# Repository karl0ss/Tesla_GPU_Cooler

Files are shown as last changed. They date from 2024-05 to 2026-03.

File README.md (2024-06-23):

# Tesla M60 GPU Cooler: An ESP8266-Based Solution for Nvidia Tesla Card Cooling

## Introduction

Starting a journey to build a cost-effective system for running large language models (LLMs) using [Ollama](https://ollama.com/) led me to discover Nvidia Tesla cards. These older cards, designed for server farms, boast substantial VRAM and are now available at affordable prices on eBay. After finding out that the Nvidia Tesla M60 supports Ollama and purchasing one, I realized these cards lack active cooling, necessitating a DIY solution for effective cooling.

## Overview of Existing Solutions

### 3D Printable Shroud with Dell Radial Fan

The first solution I encountered was a 3D printable shroud designed for the M40 card, which could be paired with a Dell radial fan. However, the shroud didn't fit my M60 due to dimensional differences and PSU connector placement. Modifying the Fusion 360 file, I created a shroud specifically for the M60. This design still required repinning the fan, which wasn't ideal as I lacked spare fan headers on my motherboard.

3D Printable Shroud

### PiPico-Based Fan Controller

The next project, [Tesla Cooler](https://github.com/tesla-cooler), used a PiPico and several small fans to cool the card. This setup controlled fan speed based on estimated temperatures derived from the `nvidia-smi` tool and a `ds18b20` temperature sensor. While innovative, I wanted a more accurate method for obtaining temperature readings and integrating them into Home Assistant.

PiPico-Based Fan Controller

### Sensors2mqtt for Accurate Temperature Readings

[Sensors2mqtt](https://github.com/koriwi/sensors2mqtt) provided a solution by scraping `nvidia-smi` data and posting it to an MQTT server, creating entities in Home Assistant. This approach offered the accuracy I needed without extensive coding, setting the foundation for my custom project.

## My Custom Solution

Integrating the best elements of these projects, I developed a comprehensive cooling system for the Tesla M60:

- **3D Printed Shroud**: Custom-designed to fit the M60, avoiding the need for repinning the fan.
- **Dell Fan**: Purchased from eBay, requiring no repinning.
- **ESP8266 Microcontroller**: Utilized for controlling the fan and connecting to Wi-Fi.
- **Nvidia SMI Data**: Used for accurate temperature readings.
- **DS18b20 Sensor**: Added as a fallback.
- **PID Controller Logic**: Maintains GPU temperature at 70°C, adjustable via Home Assistant.
- **Single 12V Line from ATX PSU**: Powers the 12V fan.
- **Custom PCB Design**: Designed a custom PCB for the ESP-12e to simplify the setup and ensure robust connections.

## The Implementation Plan

### Components and Tools

- **3D Printer**: To print the custom shroud.
- **Dell Radial Fan**: For active cooling.
- **ESP8266 (D1 Mini and ESP-12e)**: For microcontroller-based control.
- **Home Assistant**: For integration and control.
- **MQTT Server**: For data communication.
- **Nvidia SMI Tool**: For accurate temperature readings.
- **DS18b20 Temperature Sensor**: As a fallback option.
- **Custom PCB for ESP-12e**: To ensure reliable connections and ease of setup.

### Configuration with ESPHome and Home Assistant

Using [ESPHome](https://esphome.io/index.html), the ESP8266 microcontroller is configured to:

- **Connect to Wi-Fi**: Ensuring stable network communication.
- **Subscribe to MQTT Topics**: Receiving GPU temperature data.
- **Monitor Temperatures**: From both the GPU and DS18b20 sensor.
- **Control Fan Speed**: Based on temperature readings with predefined thresholds.
- **Integrate with Home Assistant**: Allowing manual override and monitoring.

### Detailed Configuration

The ESPHome YAML configuration includes several key components and functionalities:

#### Basic Setup
- **ESP8266 Microcontroller**: Configured for Wi-Fi connectivity and microcontroller operations.
- **Logger**: Enabled for logging events and debugging.
- **API and OTA**: Configured for Home Assistant API integration and over-the-air firmware updates.
- **Captive Portal**: Provides an interface for configuring Wi-Fi settings if needed.

#### Wi-Fi Configuration
- **Wi-Fi Setup**: Configures the ESP8266 to connect to the specified Wi-Fi network with static IP settings. An access point (AP) mode is also defined for initial setup or fallback.
- **Manual IP Configuration**: Ensures the ESP8266 has a stable IP address for communication.

#### MQTT Configuration
- **MQTT Integration**: Connects to the MQTT broker for sending and receiving data.
- **On Disconnect**: Sets the fan speed to 100% if the MQTT connection is lost, ensuring the GPU is always cooled.

#### Temperature Sensors
- **Dallas Sensor**: Configured on GPIO05 to provide fallback temperature readings.
- **MQTT Sensors**: Subscribes to MQTT topics for GPU temperature data provided by sensors2mqtt.

#### Global Variables
- **Global States**: Maintains the state of fan speed percentage, temperature source (GPU or Dallas sensor), maximum GPU temperature, and manual override status.

#### Switches
- **Use GPU Temperature Switch**: Toggles between using GPU temperature or Dallas sensor for controlling the fan. Disables manual override when switched.
- **Manual Fan Override Switch**: Allows manual control of the fan speed, overriding automatic temperature-based control.

#### Sensors and Outputs
- **Wi-Fi Signal Strength**: Monitors Wi-Fi connection quality.
- **Template Sensors**: For current fan speed, GPU maximum temperature, and uptime.
- **Pulse Counter**: Measures fan RPM via pulses on GPIO0.
- **PWM Output**: Controls fan speed using a PWM signal on GPIO02, with frequency set to 25 kHz.

#### Number Component
- **Fan Speed Override**: Slider in Home Assistant for manual fan speed control, activates manual override when adjusted.

#### Intervals and Scripts
- **Intervals**: Regularly update GPU temperatures, calculate maximum temperature, and adjust fan speed accordingly.
- **Adjust Fan Speed Script**: Implements the logic for fan speed adjustment based on the selected temperature sensor and current temperatures.

### Fan Speed Control Logic
TeslaGPUFan Setup
- **Below 50°C (GPU) / 40°C (Dallas)**: Fan runs at the minimum speed of 10%.
- **50°C to 65°C (GPU) / 40°C to 55°C (Dallas)**: Fan speed scales linearly between 10% to 80%.
- **Above 65°C (GPU) / 60°C (Dallas)**: Fan runs at maximum speed of 100%.

### Home Assistant Integration


In [Home Assistant](https://www.home-assistant.io/), the following functionalities are implemented:

- **Device Monitoring**: Displays real-time sensor data, fan speed, and other relevant metrics.
- **Control Switches**: Provides interface to toggle temperature source and manual override.
- **Fan Speed Adjustment**: Allows manual control through a slider interface.
- **OTA Updates**: Simplifies firmware upgrades to add features or fix issues without physical access to the device.

## PCB Design
TeslaGPUFan
The custom PCB design for the ESP-12e simplifies the setup and ensures robust connections for the cooling system. Here's a breakdown of the components and their connections:

1. **Power Supply:**
   - The circuit is powered by a 12V power supply connected to a header (HDR-F-2.54_1x2).
   - The 12V is stepped down to 3.3V using an LD1117V33C voltage regulator (U2).

2. **Voltage Regulator (U2 - LD1117V33C):**
   - Input (VIN) connected to the 12V supply.
   - Ground (GND) connected to the common ground.
   - Output (VOUT) providing 3.3V to power the ESP8266 and other components.

3. **ESP-12E (ESP8266-12E):**
   - The 3.3V supply from the voltage regulator is connected to the VCC pin of the ESP8266.
   - Various GPIO pins are connected to other components in the circuit:
     - GPIO2 is connected to the DQ pin of the DS18B20 temperature sensor through a 4.7kΩ pull-up resistor (R1).
     - GPIO4 and GPIO5 are connected to a fan through a 10kΩ resistor (R2).

4. **DS18B20 Temperature Sensor (U1):**
   - VDD connected to 3.3V.
   - GND connected to ground.
   - DQ (Data) line connected to GPIO2 of the ESP8266 through a 4.7kΩ pull-up resistor (R1).

5. **Fan:**
   - Connected to GPIO4 and GPIO5 of the ESP8266 through a 10kΩ resistor (R2).
  
- Unpopulated PCB
  
- Populated and running PCB
  

This circuit is designed for temperature monitoring using the DS18B20 sensor, with the ESP8266 controlling a fan based on the temperature readings. The ESP8266 can also provide Wi-Fi connectivity to send data to a server or a cloud service for remote monitoring.

## Summary

TeslaGPUFan provides a robust solution for controlling a GPU fan using an ESP8266 microcontroller. It combines the accuracy of `nvidia-smi` temperature readings with the fallback reliability of a DS18b20 sensor. The integration with Home Assistant and MQTT allows for advanced automation and manual control, ensuring efficient cooling under varying conditions. This project showcases the potential of DIY solutions in enhancing the functionality of affordable, high-performance hardware like the Nvidia Tesla M60.

[Link to working driver](https://www.nvidia.com/Download/driverResults.aspx/222684/en-us)

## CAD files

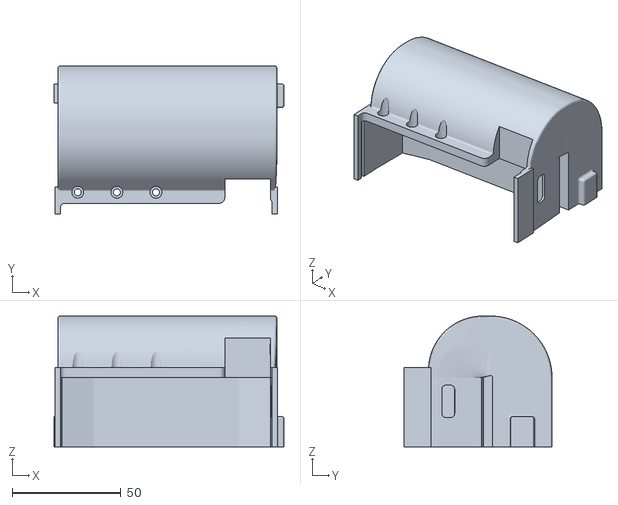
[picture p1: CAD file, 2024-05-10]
Nvidia_Tesla_M60_Blower_duct.stl
105.9 x 68.2 x 60.3

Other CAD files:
Nvidia_Tesla_M60_v9 v1.f3d

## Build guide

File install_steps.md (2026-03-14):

# On Host
`apt update && apt upgrade -y`
reboot

`apt install build-essential dkms pve-headers-$(uname -r)`

`wget https://us.download.nvidia.com/XFree86/Linux-x86_64/580.142/NVIDIA-Linux-x86_64-580.142.run`

support for steam-headless only with `wget https://download.nvidia.com/XFree86/Linux-x86_64/535.183.01/NVIDIA-Linux-x86_64-535.183.01.run`

`chmod +x NVIDIA-Linux-x86_64-580.142.run`

`./NVIDIA-Linux-x86_64-580.142.run  --dkms`

let it make changes and disable nodemon, install will fail, abort install, reboot

rerun installer
`./NVIDIA-Linux-x86_64-580.142.run  --dkms`

reboot

`nvidia-smi`

# LXC

`sudo ./NVIDIA-Linux-x86_64-580.142.run --no-kernel-module`

# Ollama

we should not edit the ollama daemon service file directly. what we should do is creating a extra config file like what docker did in its doc. in summry, you do the following stuff:

sudo mkdir /etc/systemd/system/ollama.service.d
sudo vim /etc/systemd/system/ollama.service.d/http-host.conf
sudo systemctl daemon-reload
sudo systemctl restart ollama
the content of the http-host.conf file should be:

```
[Service]
Environment="OLLAMA_HOST=0.0.0.0"
```
after all this, you can tell ollama is indeed serving on all interfaces by sudo systemctl status ollama, there will be logs like Listening on [::]:11434

No need for alarm; This already happens when you run systemctl edit ollama.service

# Proxmox passthrough

`sudo usermod -aG video,render,input,xrdp,sudo,syslog usernamehere`

`sudo apt install pkg-config libglvnd-dev`

```
lxc.idmap: u 0 100000 65536
lxc.idmap: g 0 100000 65536
lxc.cgroup2.devices.allow: c 195:* rwm
lxc.cgroup2.devices.allow: c 534:* rwm
lxc.mount.entry: /dev/nvidia0 dev/nvidia0 none bind,optional,create=file
lxc.mount.entry: /dev/nvidia1 dev/nvidia1 none bind,optional,create=file
lxc.mount.entry: /dev/nvidiactl dev/nvidiactl none bind,optional,create=file
lxc.mount.entry: /dev/nvidia-uvm dev/nvidia-uvm none bind,optional,create=file
lxc.mount.entry: /dev/nvidia-uvm-tools dev/nvidia-uvm-tools none bind,optional,c

```

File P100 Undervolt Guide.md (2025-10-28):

# 🖥️ Tesla P100 Power & Clock Profiles (Linux, Debian)

This guide shows how to run a **Tesla P100** headless server more efficiently using `nvidia-smi` and `systemd`.

---

## 🔧 Installation

### 1. Create the profile script
Save as `/usr/local/sbin/gpu-profile`:

```bash
#!/usr/bin/env bash
set -euo pipefail

PROFILE="${1:-}"

if [[ -z "${PROFILE}" || "${PROFILE}" == "-h" || "${PROFILE}" == "--help" ]]; then
  cat <<'USAGE'
Usage: gpu-profile <balanced|eco|stock|status>

Profiles:
  balanced : PL=200W, mem=715 MHz, gfx=1180 MHz   (good efficiency, near-full perf)
  eco      : PL=175W, mem=715 MHz, gfx=1013 MHz   (max efficiency, lower peak perf)
  stock    : reset to vendor defaults
Commands:
  status   : show current power limits and clocks
USAGE
  exit 0
fi

apply_all() {
  local pl="$1" mem="$2" gfx="$3"
  nvidia-smi -pm 1 >/dev/null

  while IFS=',' read -r idx minlim maxlim; do
    req_pl=$(awk -v req="$pl" -v min="$minlim" -v max="$maxlim" 'BEGIN{
      v=req; if (v<min) v=min; if (v>max) v=max; printf("%.2f", v)
    }')

    echo "[GPU $idx] PL=${req_pl}W mem=${mem} gfx=${gfx}"
    nvidia-smi -i "$idx" -pm 1
    nvidia-smi -i "$idx" -pl "$req_pl"
    nvidia-smi -i "$idx" -ac "${mem},${gfx}"
  done < <(nvidia-smi --query-gpu=index,power.min_limit,power.max_limit --format=csv,noheader,nounits)
}

case "${PROFILE}" in
  balanced) apply_all 200 715 1180 ;;
  eco)      apply_all 175 715 1013 ;;
  stock)
    echo "Resetting clocks and power limits..."
    nvidia-smi -rac
    while read -r idx defpl; do
      echo "[GPU $idx] Restoring PL=${defpl}"
      nvidia-smi -i "$idx" -pl "${defpl% *}"
    done < <(nvidia-smi --query-gpu=index,power.default_limit --format=csv,noheader)
    ;;
  status)   nvidia-smi -q -d POWER,CLOCK; exit 0 ;;
  *)        echo "Unknown profile: ${PROFILE}" >&2; exit 1 ;;
esac

echo
nvidia-smi -q -d POWER,CLOCK | sed -n '1,200p'
```

Make it executable:
```bash
sudo chmod 755 /usr/local/sbin/gpu-profile
```

---

### 2. Create the systemd service

File: `/etc/systemd/system/nvidia-24x7-tune.service`
```ini
[Unit]
Description=Apply NVIDIA 24/7 efficiency tuning at boot
After=multi-user.target
ConditionPathExists=/proc/driver/nvidia

[Service]
Type=oneshot
# Default profile (Balanced). Override with drop-ins.
ExecStart=/usr/local/sbin/gpu-profile balanced
RemainAfterExit=true

[Install]
WantedBy=multi-user.target
```

Enable it:
```bash
sudo systemctl daemon-reload
sudo systemctl enable --now nvidia-24x7-tune.service
```

---

## ⚡ Profiles

**Stock (default)**  
- PL: 250 W (default)  
- Clocks: Memory 715 MHz, Graphics up to ~1328–1480 MHz

```bash
sudo gpu-profile stock
```

**Balanced (default at boot)**  
- PL: 200 W  
- Clocks: Memory 715 MHz, Graphics 1180 MHz  
- ✅ Good 24/7 mode: ~90–95% performance, ~20–25% less power/heat

```bash
sudo gpu-profile balanced
```

**Eco**  
- PL: 175 W  
- Clocks: Memory 715 MHz, Graphics 1013 MHz  
- ✅ Maximum efficiency: ~80–85% performance, cooler & quieter

```bash
sudo gpu-profile eco
```

---

## 🌀 Switching Profiles Live

All changes take effect immediately without reboot:

```bash
sudo gpu-profile eco
sudo gpu-profile balanced
sudo gpu-profile stock
```

---

## 🔒 Notes

- **Safe**: All values use NVIDIA’s supported limits; you can’t undervolt below the card’s firmware min.
- **Auto Boost**: Leaving it ON is fine; power limits keep things safe. Turn it OFF if you want strictly fixed clocks.
- **Service default**: Balanced is applied at boot. Use `systemctl edit nvidia-24x7-tune.service` to change.

---

## 🧪 Validation Commands

After applying a profile, verify:

```bash
sudo gpu-profile status
```

Expected output should show:
```
Power Draw: ~175–200 W
Clocks: Graphics 1013/1180 MHz, Memory 715 MHz
```

To check available ranges:

```bash
nvidia-smi --query-gpu=index,power.min_limit,power.max_limit,power.default_limit --format=csv
nvidia-smi -q -d SUPPORTED_CLOCKS
```

---

✅ **Summary**
- Balanced = 200 W @ 1180 MHz (best 24/7 efficiency)
- Eco = 175 W @ 1013 MHz (max efficiency)
- Safe, reversible, and systemd‑automated.

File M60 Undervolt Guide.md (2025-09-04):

# 🖥️ Tesla M60 Power & Clock Profiles (Linux, Debian)

This guide shows how to run a Tesla M60 headless server more efficiently using `nvidia-smi` and `systemd`.

---

## 🔧 Installation

### 1. Create the profile script
Save as `/usr/local/sbin/gpu-profile`:

```bash
#!/usr/bin/env bash
set -euo pipefail

PROFILE="${1:-}"

if [[ -z "${PROFILE}" || "${PROFILE}" == "-h" || "${PROFILE}" == "--help" ]]; then
  cat <<'USAGE'
Usage: gpu-profile <balanced|eco|stock|status>

Profiles:
  balanced : PL=120W, mem=2505 MHz, gfx=873 MHz   (good efficiency, near-full perf bursts)
  eco      : PL=112.5W, mem=2505 MHz, gfx=759 MHz (max efficiency, lower peak perf)
  stock    : reset to vendor defaults
Commands:
  status   : show current power limits and clocks
USAGE
  exit 0
fi

apply_all() {
  local pl="$1" mem="$2" gfx="$3"
  nvidia-smi -pm 1 >/dev/null

  while IFS=',' read -r idx minlim maxlim; do
    req_pl=$(awk -v req="$pl" -v min="$minlim" -v max="$maxlim" 'BEGIN{
      v=req; if (v<min) v=min; if (v>max) v=max; printf("%.2f", v)
    }')

    echo "[GPU $idx] PL=${req_pl}W mem=${mem} gfx=${gfx}"
    nvidia-smi -i "$idx" -pm 1
    nvidia-smi -i "$idx" -pl "$req_pl"
    nvidia-smi -i "$idx" -ac "${mem},${gfx}"
  done < <(nvidia-smi --query-gpu=index,power.min_limit,power.max_limit --format=csv,noheader,nounits)
}

case "${PROFILE}" in
  balanced) apply_all 120 2505 873 ;;
  eco)      apply_all 112.5 2505 759 ;;
  stock)
    echo "Resetting clocks and power limits..."
    nvidia-smi -rac
    while read -r idx defpl; do
      echo "[GPU $idx] Restoring PL=${defpl}"
      nvidia-smi -i "$idx" -pl "${defpl% *}"
    done < <(nvidia-smi --query-gpu=index,power.default_limit --format=csv,noheader)
    ;;
  status)   nvidia-smi -q -d POWER,CLOCK; exit 0 ;;
  *)        echo "Unknown profile: ${PROFILE}" >&2; exit 1 ;;
esac

echo
nvidia-smi -q -d POWER,CLOCK | sed -n '1,200p'
```
Make it executable:
```bash
sudo chmod 755 /usr/local/sbin/gpu-profile
```

2. Create the systemd service

File: `/etc/systemd/system/nvidia-24x7-tune.service`
```ini
[Unit]
Description=Apply NVIDIA 24/7 efficiency tuning at boot
After=multi-user.target
ConditionPathExists=/proc/driver/nvidia

[Service]
Type=oneshot
# Default profile (Balanced). Override with drop-ins.
ExecStart=/usr/local/sbin/gpu-profile balanced
RemainAfterExit=true

[Install]
WantedBy=multi-user.target
```

Enable it:
```basg
sudo systemctl daemon-reload
sudo systemctl enable --now nvidia-24x7-tune.service
```

⚡ Profiles
Stock

 - PL: 150 W (default)
 - Clocks: Memory 2505 MHz, Graphics up to 1177 MHz
```bash
sudo gpu-profile stock
```
Balanced (default at boot)

  - PL: 120 W
  - Clocks: Memory 2505 MHz, Graphics 873 MHz
  - ✅ Good 24/7 mode: ~90–95% performance, ~20–25% less power/heat
```bash
sudo gpu-profile balanced
```
Eco

  - PL: 112.5 W (minimum allowed)
  - Clocks: Memory 2505 MHz, Graphics 759 MHz
  - ✅ Maximum efficiency: ~70–80% performance, cooler & quieter
```bash
sudo gpu-profile eco
```

🌀 Switching Profiles Live

  - Eco:
```bash
sudo gpu-profile eco
```
 - Balanced:
```bash
sudo gpu-profile balanced
```
 - Stock:
```bash
sudo gpu-profile stock
```
These changes take effect immediately without reboot.

🔒 Notes
  - Safe: All values use NVIDIA’s supported limits; you can’t “undervolt” below what the card allows.
  - Auto Boost: Leaving it ON is fine; the power limit keeps things safe. Turn it OFF if you want strictly fixed clocks.
  - Service default: Balanced is applied at boot. Use systemctl edit nvidia-24x7-tune.service to change.

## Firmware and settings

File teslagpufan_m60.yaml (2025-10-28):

substitutions:
  friendly_name: TeslaM60Fan
  gpu1_topic: sensors2mqtt/nvidia-smi/00000000_06_00_0
  gpu2_topic: sensors2mqtt/nvidia-smi/00000000_07_00_0
  temp_low: "60.0"
  temp_high: "80.0"
  fan_min: "5.0"
  fan_max: "100.0"

esphome:
  name: "teslam60fan"
  friendly_name: ${friendly_name}

  on_boot:
    priority: -100
    then:
      - output.set_level:
          id: fan_speed
          level: 1.0
      - globals.set:
          id: fan_speed_percent
          value: "100.0"
      - logger.log: "Safe-boot: fan set to 100% until GPU data received."

esp8266:
  board: esp01_1m

logger:
  level: INFO

web_server:
  port: 80

ota:
  password: "17300c7bac4a847d2b255aca0f4620e3"

captive_portal:

wifi:
  ssid: Hudgell-Wifi
  password: !secret wifi_password
  reboot_timeout: 1min
  manual_ip:
    static_ip: 192.168.4.105
    gateway: 192.168.4.1
    subnet: 255.255.255.0

  ap:
    ssid: "TeslaM60Fan-Esp12E"
    password: "S0tDmOp8vq0n"

mqtt:
  broker: 192.168.4.196
  username: mosquitto
  password: !secret mqtt_pass
  reboot_timeout: 10min
  on_disconnect:
    then:
      - lambda: |-
          ESP_LOGW("main", "MQTT disconnected — forcing fan to 100%%");
          id(fan_speed_percent) = 100.0;
          id(fan_speed).set_level(1.0);

# ───────────────────────────────────────────────────────────────
# Globals
globals:
  - id: fan_speed_percent
    type: float
    initial_value: '0.0'
  - id: gpu_max_temp
    type: float
    initial_value: '0.0'
  - id: manual_override
    type: bool
    initial_value: 'false'
  - id: last_update
    type: uint32_t
    initial_value: '0'
  - id: json_error_count
    type: int
    initial_value: '0'

# ───────────────────────────────────────────────────────────────
# Switches
switch:
  - platform: restart
    name: "${friendly_name} Restart"

  - platform: template
    name: "Manual Fan Override"
    id: manual_override_switch
    lambda: |-
      return id(manual_override);
    turn_on_action:
      - globals.set:
          id: manual_override
          value: "true"
      - logger.log: "Manual Fan Override enabled"
    turn_off_action:
      - globals.set:
          id: manual_override
          value: "false"
      - logger.log: "Manual Fan Override disabled"
    restore_mode: ALWAYS_OFF

# ───────────────────────────────────────────────────────────────
# Text Sensors
text_sensor:
  - platform: wifi_info
    ip_address:
      name: ${friendly_name} IP Address

  - platform: template
    name: ${friendly_name} Uptime
    id: uptime_human
    icon: mdi:clock-start

  - platform: mqtt_subscribe
    name: "GPU 1 Temp"
    internal: true
    id: gpu_1_temp
    topic: ${gpu1_topic}

  - platform: mqtt_subscribe
    name: "GPU 2 Temp"
    internal: true
    id: gpu_2_temp
    topic: ${gpu2_topic}

# ───────────────────────────────────────────────────────────────
# Sensors
sensor:
  - platform: wifi_signal
    name: WiFi Strength
    update_interval: 30s

  - platform: template
    name: "GPU 1 Temperature"
    id: gpu_1_temp_sensor
    unit_of_measurement: "°C"
    update_interval: never

  - platform: template
    name: "GPU 2 Temperature"
    id: gpu_2_temp_sensor
    unit_of_measurement: "°C"
    update_interval: never

  - platform: template
    name: "GPU Maximum Temperature"
    id: gpu_max_temp_sensor
    unit_of_measurement: "°C"
    lambda: |-
      return id(gpu_max_temp);
    update_interval: 5s

  - platform: template
    name: "Current Fan Speed"
    lambda: 'return round(id(fan_speed_percent));'
    unit_of_measurement: '%'
    update_interval: 5s

  - platform: template
    name: "JSON Parse Errors"
    lambda: "return id(json_error_count);"
    update_interval: 30s

  - platform: pulse_counter
    pin: GPIO0
    name: Fan RPM
    id: fan_RPM_pulse
    unit_of_measurement: 'RPM'
    filters:
      - multiply: 0.5
    count_mode:
      rising_edge: INCREMENT
      falling_edge: DISABLE
    update_interval: 10s

# ───────────────────────────────────────────────────────────────
# Output
output:
  - platform: esp8266_pwm
    id: fan_speed
    pin: GPIO02
    frequency: "25000 Hz"
    min_power: 5%
    max_power: 100%

# ───────────────────────────────────────────────────────────────
# Fan Override
number:
  - platform: template
    name: "Fan Speed Override"
    id: fan_speed_override
    max_value: 100.0
    min_value: 0.0
    step: 5
    mode: slider
    on_value:
      then:
        - globals.set:
            id: manual_override
            value: "true"
        - output.set_level:
            id: fan_speed
            level: !lambda "return x / 100.0;"
        - lambda: |-
            id(fan_speed_percent) = x;
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

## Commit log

2024-05-10 V1 PCB Design with ESP-12E
2024-05-10 Remixed STL file for Tesla M60
    [Nvidia_Tesla_M60_Blower_duct.stl]
2024-05-16 Update latest.yaml
    Add PID Controller logic to YAML
2024-05-19 Update latest.yaml
    try work out the average of both sensors, now using the correct values from sensors2mqtt, and use the average as the temp reading for calculations
2024-05-20 Update latest.yaml
    working highest sensor
2025-10-28 Add ESPHome configuration for TeslaGPUFan
    This YAML configuration sets up an ESPHome device for controlling a GPU fan, including WiFi, MQTT, and sensor configurations.
2025-10-28 Add configuration for Tesla P100 fan control
    This YAML configuration sets up a fan control system for a Tesla P100 GPU, including temperature thresholds, MQTT settings, and various sensors.
2025-10-28 Refactor configuration and fan speed logic
    Updated WiFi SSID, removed unused GPU temperature switch, and adjusted fan speed logic.
2025-10-28 Modify TeslaGPUFan configuration for M60
    Updated configuration for Tesla M60 fan with new topics and temperature settings.
2025-10-28 Create Tesla P100 Undervolt Guide
    Added a comprehensive guide for Tesla P100 undervolting, including installation steps for a profile script and systemd service, along with usage instructions for different power profiles.
2025-10-30 Update GPU fan configuration and logic
2026-03-14 Revise NVIDIA driver installation instructions
    Updated NVIDIA driver installation steps with new version and removed outdated links.
